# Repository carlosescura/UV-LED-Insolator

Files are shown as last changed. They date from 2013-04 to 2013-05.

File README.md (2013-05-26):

#UV-LED-Insolator#

### UV LED insolator for homemade PCB ###
---------------------------------

  This is a homemade UV-LED insolator aimed to do the "DIY" PCB in home.
  
All you need to build it is:

  1. Two pieces of PCB for the timer and the UV-LED backplate.
  2. An Arduino Mini Pro
  3. Any kind of the popular "16x2" LCD parallel LCD
  4. Some electronics (resistors, pushbuttons, pin headers...)

Let's do it!

More info: [Carlitosspedia](http://www.carlitosspedia.info)

[www.carlitosspedia.info](http://www.carlitosspedia.info)

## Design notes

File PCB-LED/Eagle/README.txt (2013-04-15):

This homemade insolator is designed for a 165x125mm single side board or more.

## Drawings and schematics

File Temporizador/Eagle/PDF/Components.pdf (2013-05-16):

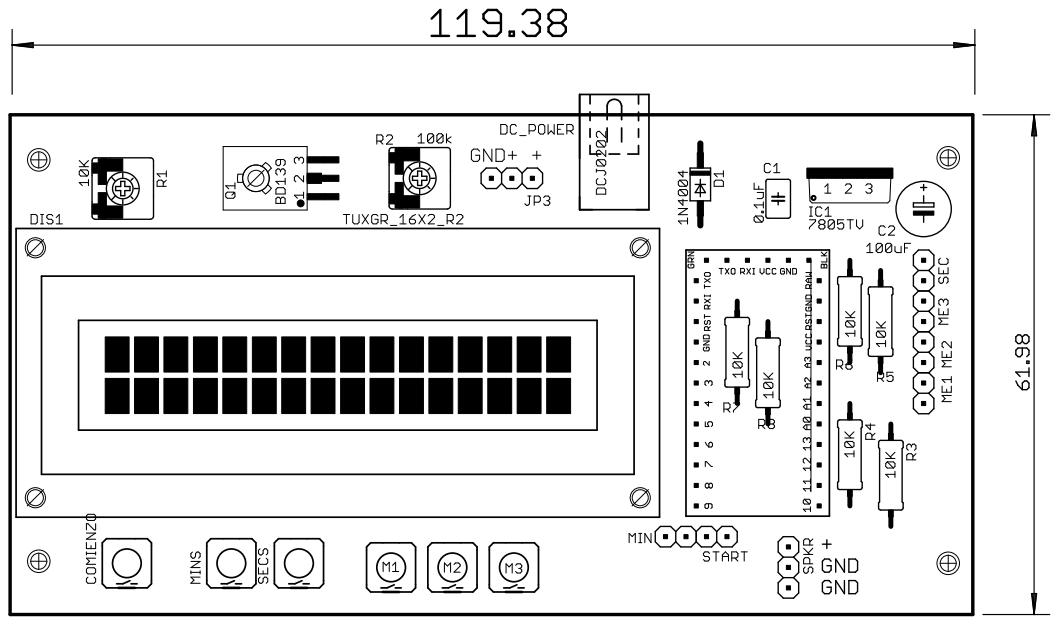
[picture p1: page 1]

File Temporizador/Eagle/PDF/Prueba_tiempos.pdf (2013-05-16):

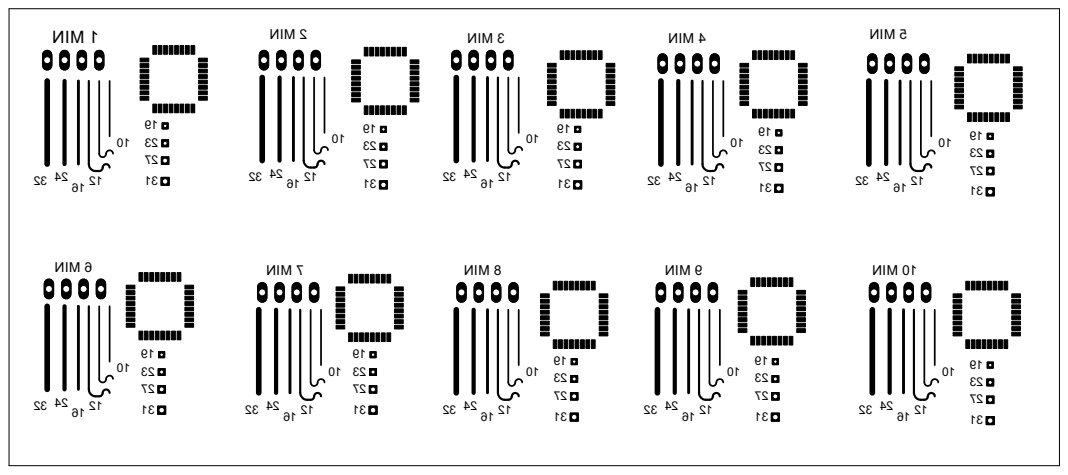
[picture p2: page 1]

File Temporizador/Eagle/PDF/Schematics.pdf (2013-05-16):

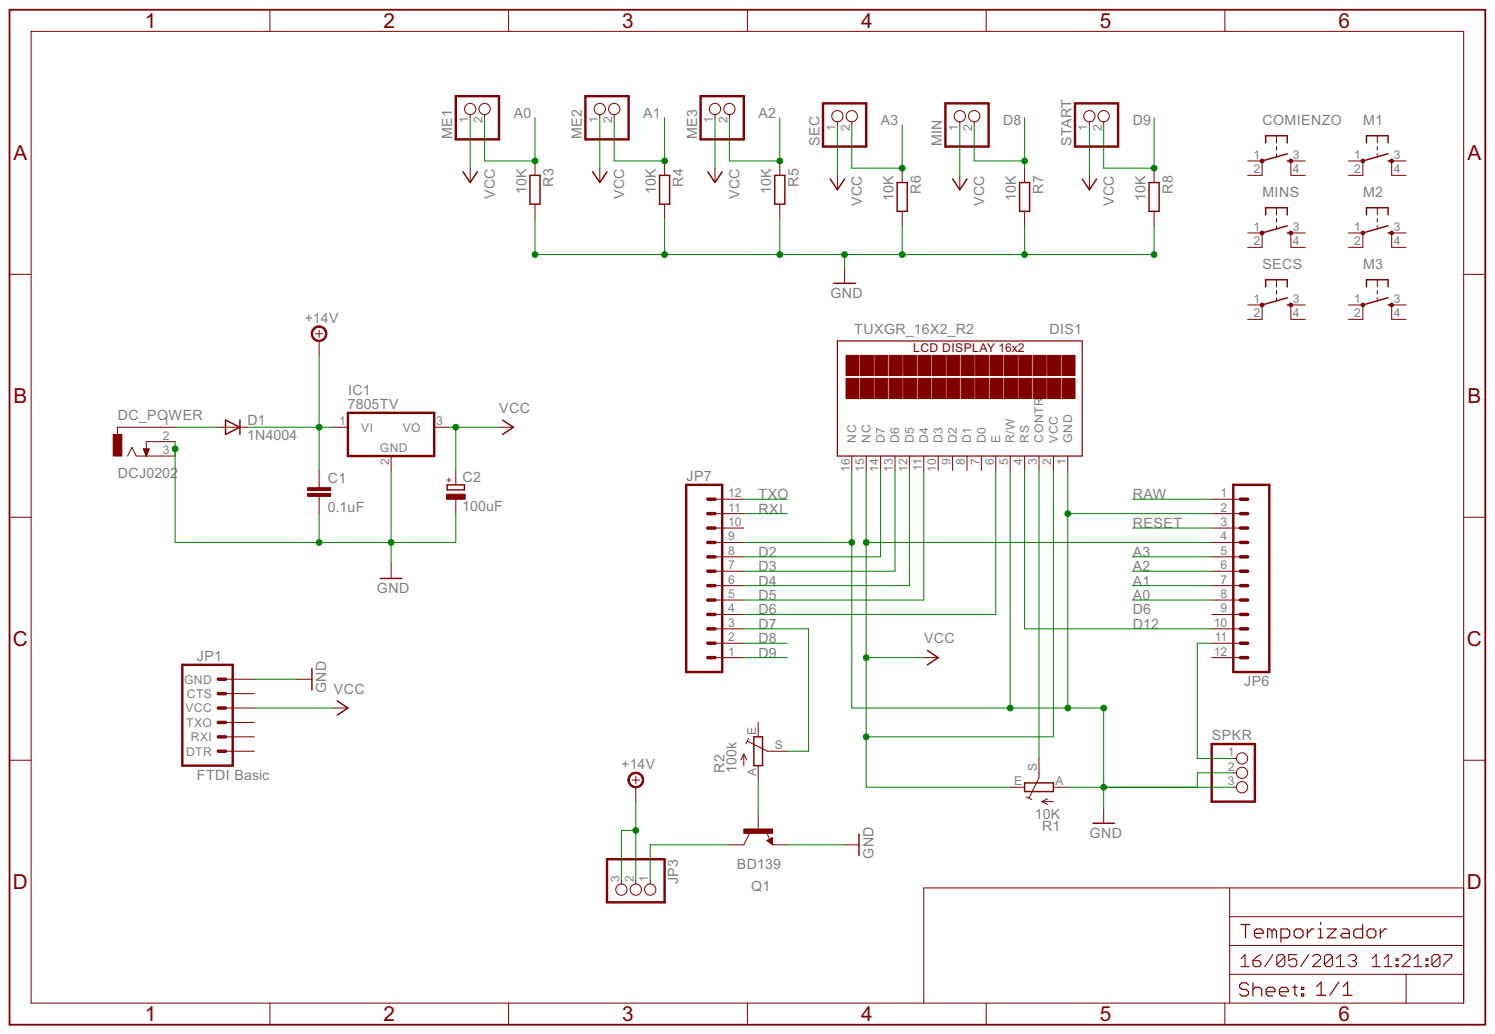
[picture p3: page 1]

8 D2 | A3 5 A2 6 A1 7 A0 8 9 D6 D12
7 D3
6 D4
5 D5
4 D6

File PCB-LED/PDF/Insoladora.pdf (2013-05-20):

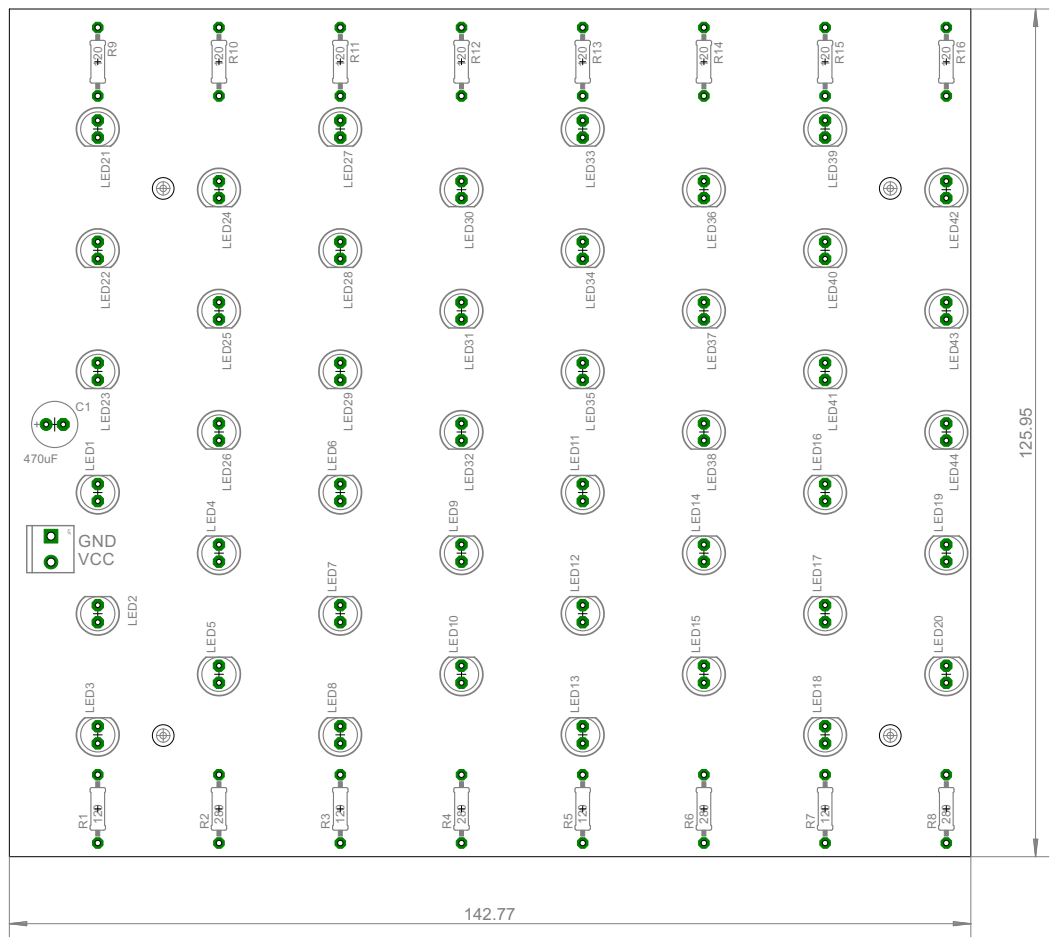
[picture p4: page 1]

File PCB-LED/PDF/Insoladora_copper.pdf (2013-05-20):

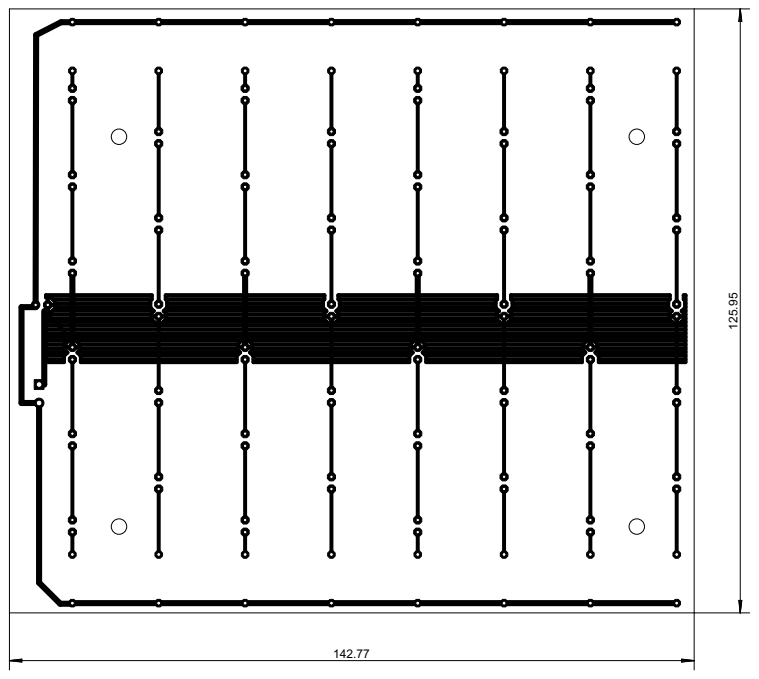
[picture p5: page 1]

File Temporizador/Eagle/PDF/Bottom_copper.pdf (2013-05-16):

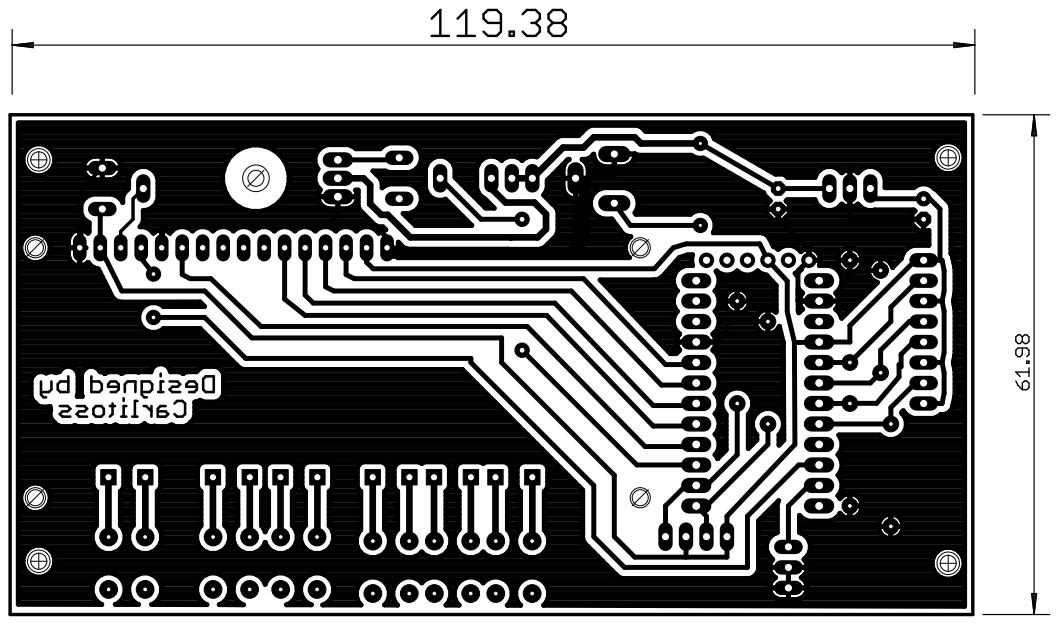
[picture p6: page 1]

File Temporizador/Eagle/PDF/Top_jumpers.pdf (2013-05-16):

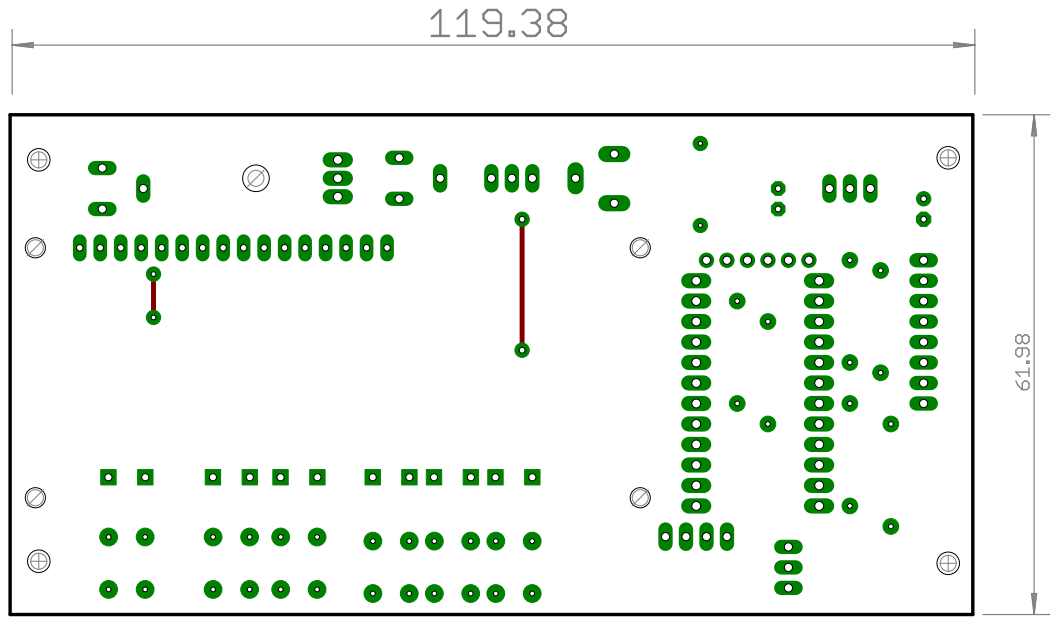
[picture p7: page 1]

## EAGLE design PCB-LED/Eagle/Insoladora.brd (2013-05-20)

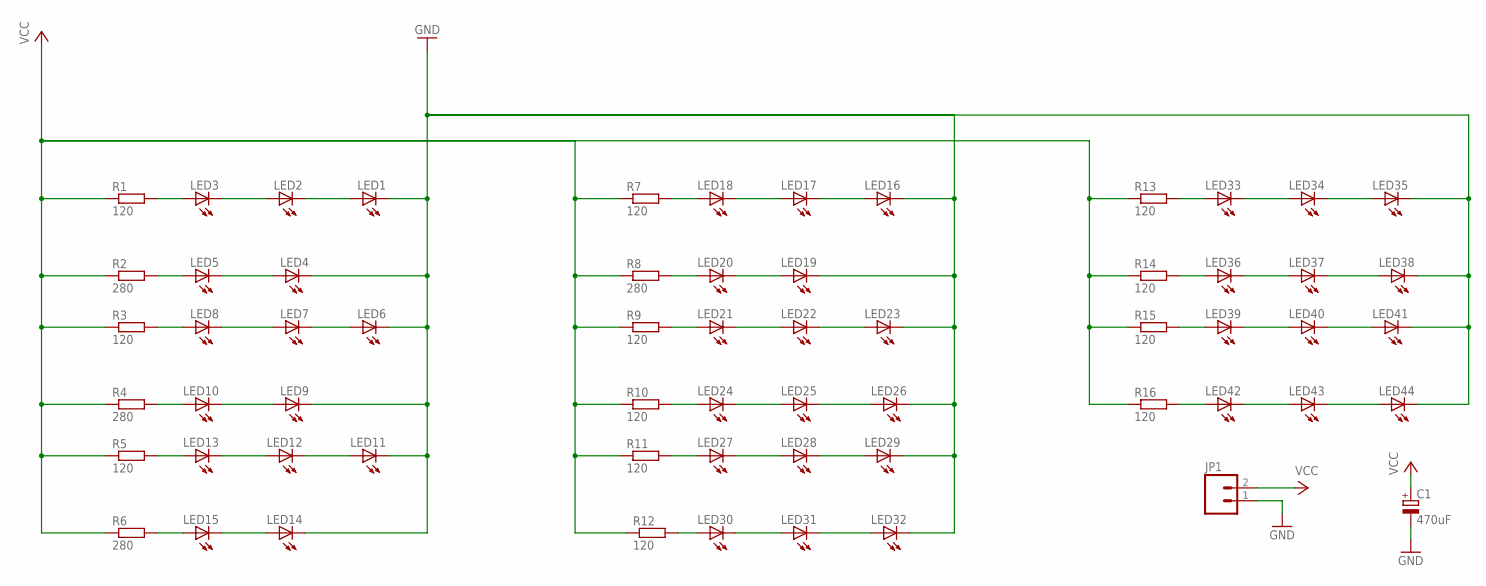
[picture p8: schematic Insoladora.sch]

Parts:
C1: 470uF; E2,5-7
JP1: M023.5MM_LOCK; SCREWTERMINAL-3.5MM-2_LOCK
LED1, LED2, LED3, LED4, LED5, LED6, LED7, LED8, LED9, LED10, LED11, LED12, LED13, LED14, LED15, LED16, LED17, LED18, LED19, LED20, LED21, LED22, LED23, LED24, LED25, LED26, LED27, LED28, LED29, LED30, LED31, LED32, LED33, LED34, LED35, LED36, LED37, LED38, LED39, LED40, LED41, LED42, LED43, LED44: LED5MM
R1, R3, R5, R7, R9, R10, R11, R12, R13, R14, R15, R16: 120; 0207/10
R2, R4, R6, R8: 280; 0207/10

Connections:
GND: C1.-, JP1.1, LED1.K (C), LED4.K (C), LED6.K (C), LED9.K (C), LED11.K (C), LED14.K (C), LED16.K (C), LED19.K (C), LED23.K (C), LED26.K (C), LED29.K (C), LED32.K (C), LED35.K (C), LED38.K (C), LED41.K (C), LED44.K (C)
unnamed: LED3.A, R1.2
unnamed: LED2.A, LED3.K (C)
unnamed: LED1.A, LED2.K (C)
unnamed: LED5.A, R2.2
unnamed: LED4.A, LED5.K (C)
unnamed: LED8.A, R3.2
unnamed: LED7.A, LED8.K (C)
unnamed: LED21.A, R9.2
unnamed: LED6.A, LED7.K (C)
unnamed: LED24.A, R10.2
unnamed: LED10.A, R4.2
unnamed: LED9.A, LED10.K (C)
unnamed: LED30.A, R12.2
unnamed: LED13.A, R5.2
unnamed: LED42.A, R16.2
unnamed: LED21.K (C), LED22.A
unnamed: LED22.K (C), LED23.A
unnamed: LED33.A, R13.2
unnamed: LED18.A, R7.2
unnamed: LED12.A, LED13.K (C)
unnamed: LED17.A, LED18.K (C)
unnamed: LED16.A, LED17.K (C)
unnamed: LED11.A, LED12.K (C)
unnamed: LED24.K (C), LED25.A
unnamed: LED25.K (C), LED26.A
unnamed: LED15.A, R6.2
unnamed: LED27.K (C), LED28.A
unnamed: LED28.K (C), LED29.A
unnamed: LED14.A, LED15.K (C)
unnamed: LED30.K (C), LED31.A
unnamed: LED31.K (C), LED32.A
unnamed: LED20.A, R8.2
unnamed: LED33.K (C), LED34.A
unnamed: LED34.K (C), LED35.A
unnamed: LED19.A, LED20.K (C)
unnamed: LED36.K (C), LED37.A
unnamed: LED37.K (C), LED38.A
unnamed: LED39.K (C), LED40.A
unnamed: LED40.K (C), LED41.A
unnamed: LED42.K (C), LED43.A
unnamed: LED43.K (C), LED44.A
unnamed: LED27.A, R11.2
unnamed: LED36.A, R14.2
unnamed: LED39.A, R15.2
VCC: C1.+, JP1.2, R1.1, R2.1, R3.1, R4.1, R5.1, R6.1, R7.1, R8.1, R9.1, R10.1, R11.1, R12.1, R13.1, R14.1, R15.1, R16.1

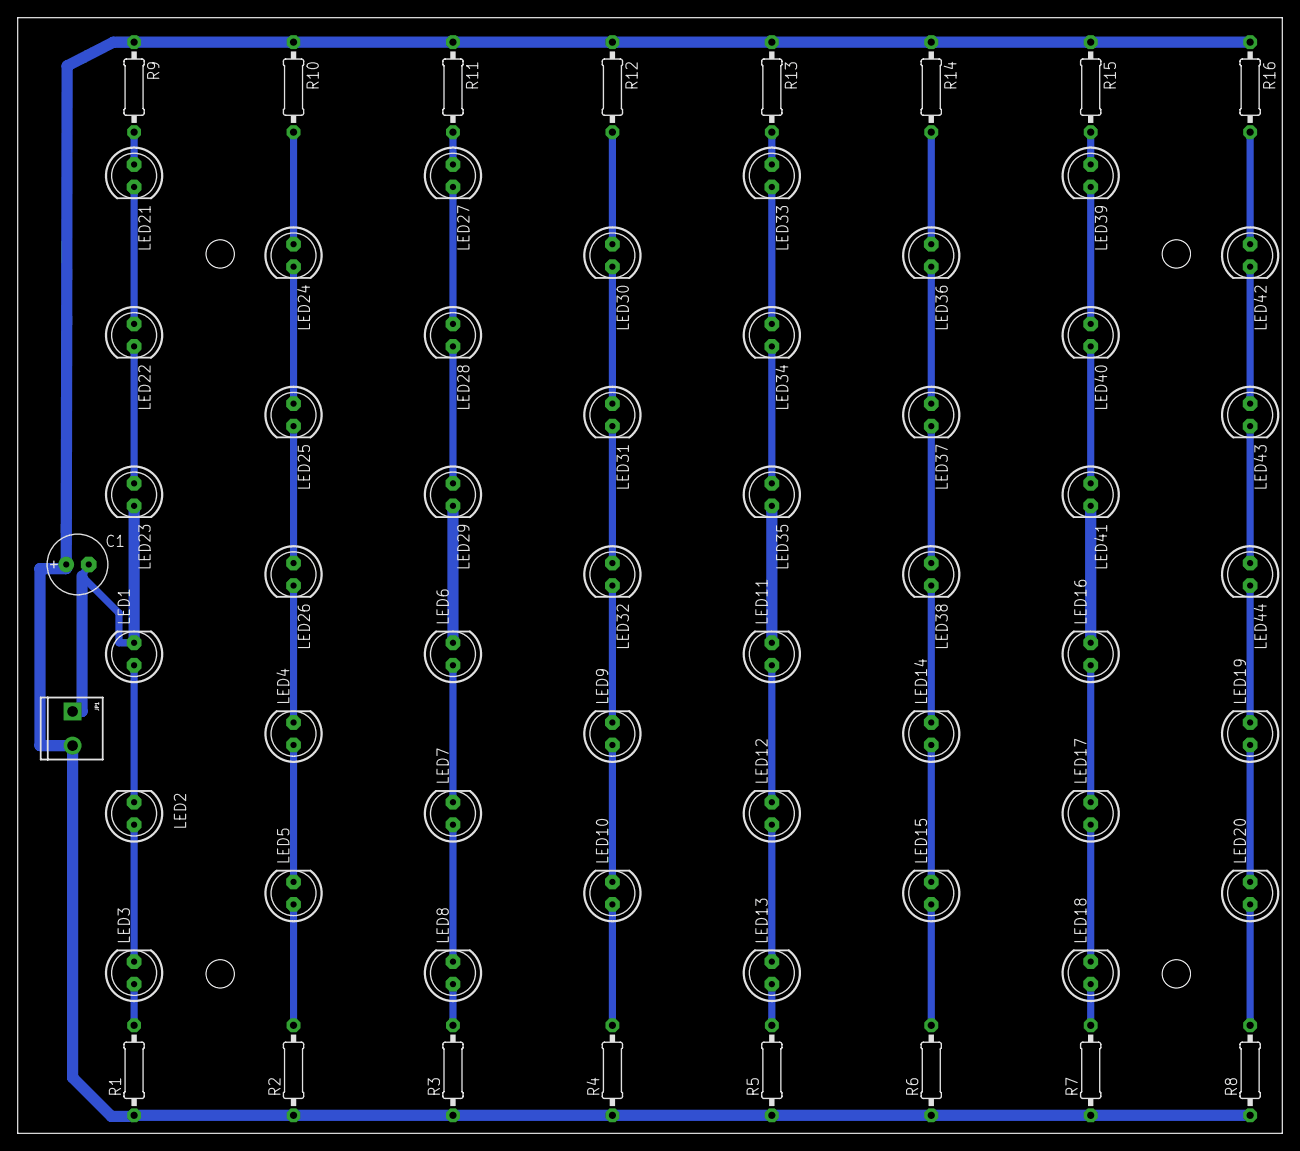
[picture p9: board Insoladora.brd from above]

Board: 2 copper layers, 142.8 x 126.0 mm, 62 parts (0 on the bottom side), 46 nets.

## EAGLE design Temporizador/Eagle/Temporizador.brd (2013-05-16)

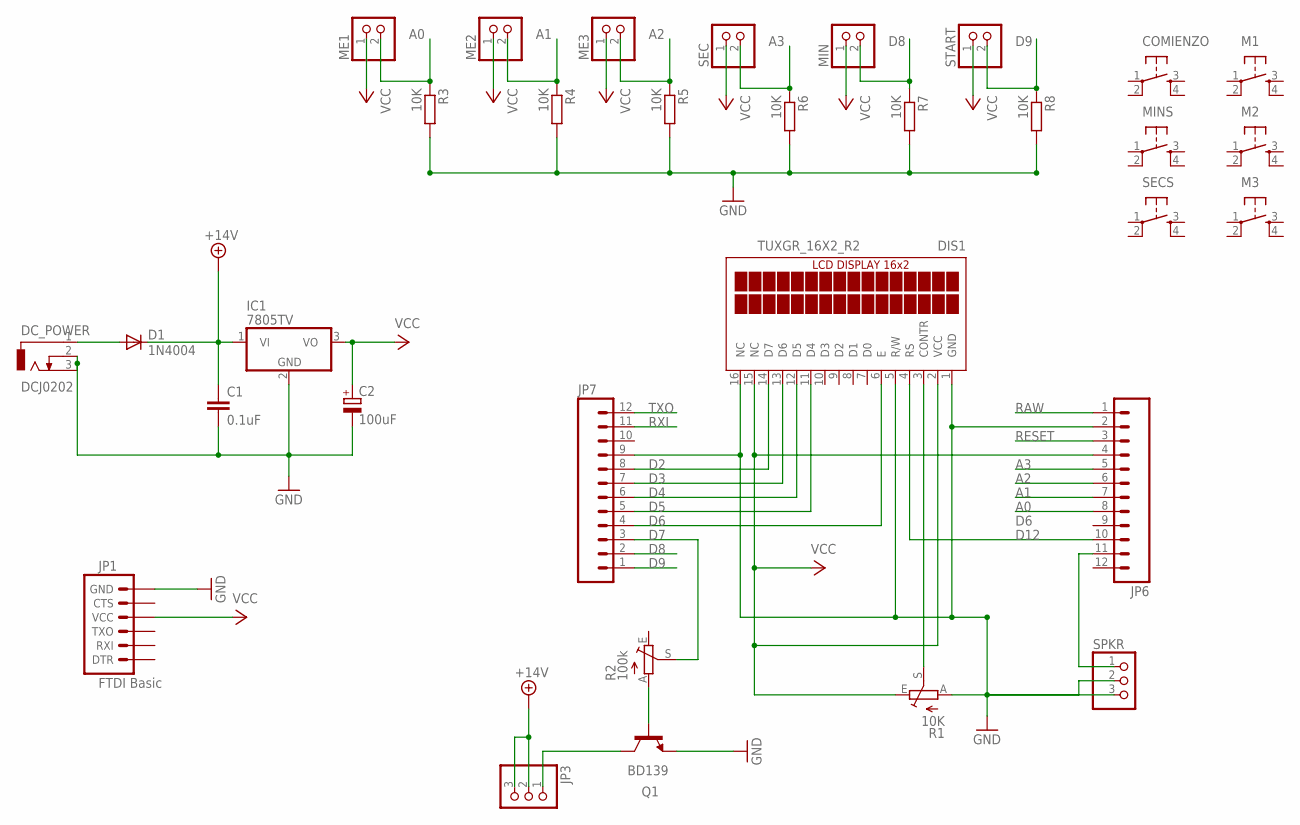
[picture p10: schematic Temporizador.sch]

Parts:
C1: 0.1uF; C025-030X050
C2: 100uF; E2,5-7
COMIENZO: TAC_SWITCHPTH; TACTILE-PTH
D1: 1N4004; DO41-10
DC_POWER: DCJ0202
DIS1: TUXGR_16X2_R2
IC1: 7805TV; TO220V
JP1: FTDI Basic; 1X06
JP3: PINHD-1X3; 1X03
JP6, JP7: M12LONGPADS; 1X12_LONGPADS
M1, M2, M3: TAC_SWITCHPTH; TACTILE-PTH
ME1, ME2, ME3: PINHD-1X2; 1X02
MIN: PINHD-1X2; 1X02
MINS: TAC_SWITCHPTH; TACTILE-PTH
Q1: BD139; TO126
R1: 10K; CA6V
R2: 100k; CA6V
R3, R4, R5, R6, R7, R8: 10K; 0309/12
SEC: PINHD-1X2; 1X02
SECS: TAC_SWITCHPTH; TACTILE-PTH
SPKR: PINHD-1X3; 1X03
START: PINHD-1X2; 1X02

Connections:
+14V: C1.1, D1.C, IC1.1 (VI), JP3.2, JP3.3
A0: JP6.8, ME1.2, R3.1
A1: JP6.7, ME2.2, R4.1
A2: JP6.6, ME3.2, R5.1
A3: JP6.5, R6.1, SEC.2
D2: DIS1.14 (D7), JP7.8
D3: DIS1.13 (D6), JP7.7
D4: DIS1.12 (D5), JP7.6
D5: DIS1.11 (D4), JP7.5
D6: DIS1.6 (E), JP7.4
D7: JP7.3, R2.S
D8: JP7.2, MIN.2, R7.1
D9: JP7.1, R8.1, START.2
D12: DIS1.4 (RS), JP6.10
GND: C1.2, C2.-, DC_POWER.2, DC_POWER.3, DIS1.1 (GND), DIS1.5 (R/W), DIS1.16 (NC), IC1.2 (GND), JP1.6 (GND), JP6.2, JP7.9, Q1.1 (E), R1.A, R3.2, R4.2, R5.2, R6.2, R7.2, R8.2, SPKR.2, SPKR.3
unnamed: DIS1.3 (CONTR), R1.S
unnamed: JP6.11, SPKR.1
unnamed: Q1.3 (B), R2.A
unnamed: JP3.1, Q1.2 (C)
unnamed: D1.A, DC_POWER.1
RAW: JP6.1
RESET: JP6.3
RXI: JP7.11
TXO: JP7.12
VCC: C2.+, DIS1.2 (VCC), DIS1.15 (NC), IC1.3 (VO), JP1.4 (VCC), JP6.4, ME1.1, ME2.1, ME3.1, MIN.1, R1.E, SEC.1, START.1

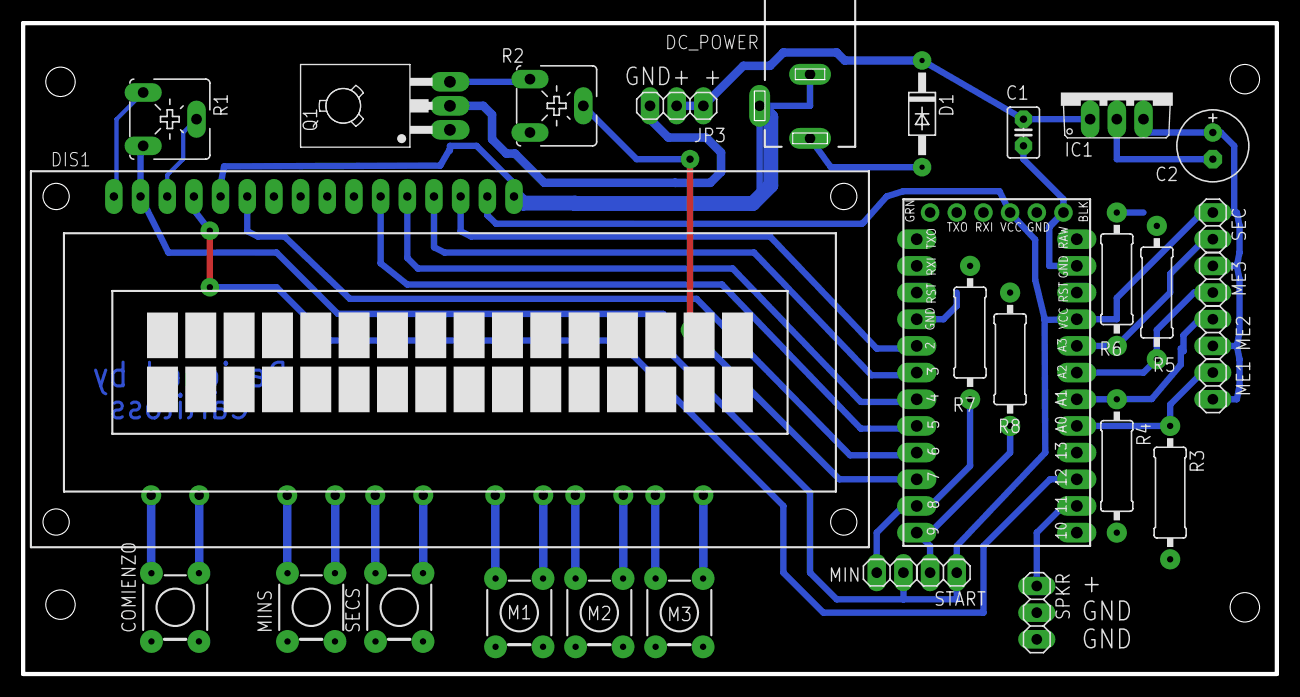
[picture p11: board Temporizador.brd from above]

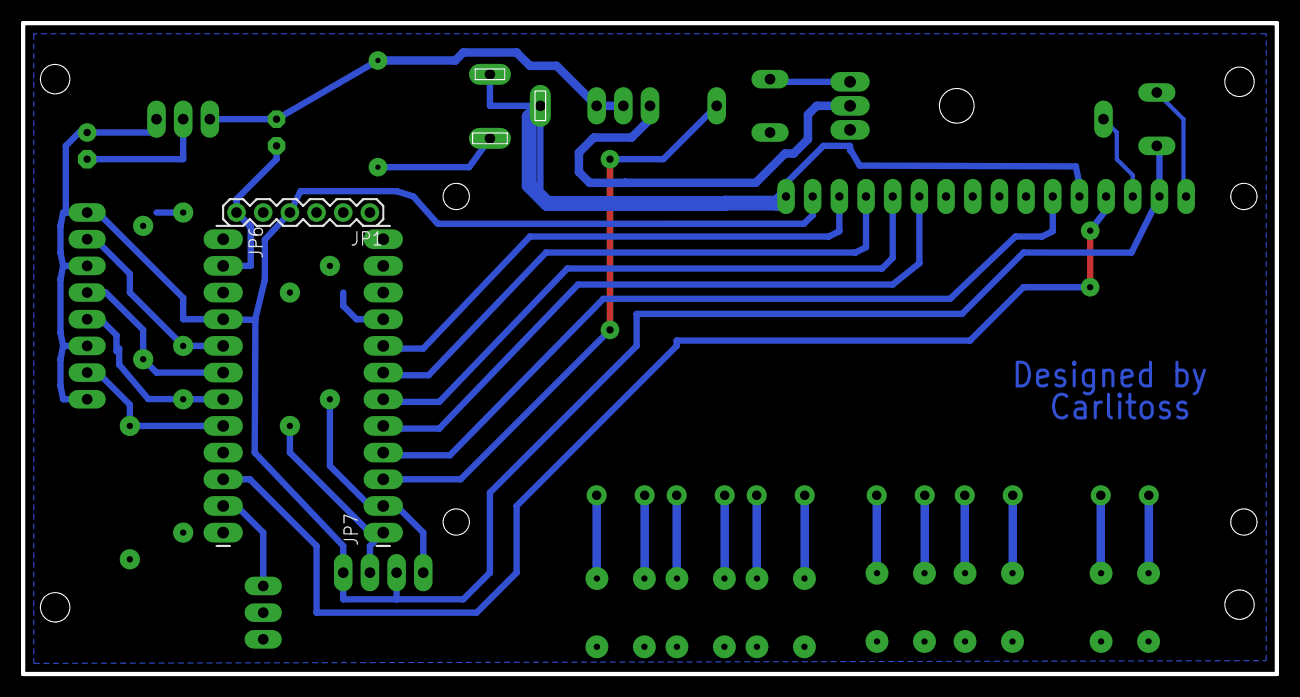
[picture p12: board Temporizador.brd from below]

Board: 2 copper layers, 119.4 x 62.0 mm, 32 parts (3 on the bottom side), 21 nets.

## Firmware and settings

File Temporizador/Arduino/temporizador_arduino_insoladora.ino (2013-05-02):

/*----------------------------------------------------- 
Author:  Carlos Escura
Date: Thu Apr 18 13:55:10 2013
Description:
*/

#include <EEPROM.h>
#include <LiquidCrystal.h>

#define Bpreset1 A0
#define Bpreset2 A1
#define Bpreset3 A2
#define Bsegundos A3
#define Bminutos 8
#define Bcomienzo 9

#define pinSalida 7

#define MApreset1 1
#define MApreset2 2
#define MApreset3 3






//--------------------------CANCIONES----------------------------//

int speakerPin = 11;
//speaker connected to one of the PWM ports
 
#define c 261
#define d 294
#define e 329
#define f 349
#define g 391
#define gS 415
#define a 440
#define aS 455
#define b 466
#define cH 523
#define cSH 554
#define dH 587
#define dSH 622
#define eH 659
#define fH 698
#define fSH 740
#define gH 784
#define gSH 830
#define aH 880


//------------------------//

 
//Tiempo
byte minutos;
byte segundos;

// LiquidCrystal lcd(RS, E, D4, D5, D6, D7);
LiquidCrystal lcd(12, 6, 5, 4, 3, 2);


void setup() {
   
   pinMode(Bcomienzo, INPUT);
   pinMode(Bminutos, INPUT);
   pinMode(Bsegundos, INPUT);
   pinMode(pinSalida, OUTPUT);
   pinMode(Bpreset1, INPUT);
   pinMode(Bpreset2, INPUT);
   pinMode(Bpreset3, INPUT);
   pinMode(speakerPin, OUTPUT); 
   //pinMode(buzzerPin, OUTPUT);
  
  lcd.begin(16, 2);
  lcd.setCursor(3,0);
  lcd.print("INSOLADORA");
  lcd.setCursor(5,1);
  lcd.print("LED-UV");
  delay(3000);
    
  lcd.clear();
  
    
  lcd.setCursor(4,0);
  lcd.print("SELECCION");
  lcd.setCursor(0,1);
  lcd.print("TIEMPO INSOLADO");
  
  delay(3000);
  lcd.clear();
    
  minutos = 0;
  segundos = 0;  
 
}


///////////////-----------------------------------------------------------------/////
//////////////--------------------------MARCHA IMPERIAL ------------------------/////



void beep (unsigned char speakerPin, int frequencyInHertz, long timeInMilliseconds)
{ 
   
    
    int x; 	 
    long delayAmount = (long)(1000000/frequencyInHertz);
    long loopTime = (long)((timeInMilliseconds*1000)/(delayAmount*2));
    for (x=0;x<loopTime;x++) 	 
    { 	 
        digitalWrite(speakerPin,HIGH);
        delayMicroseconds(delayAmount);
        digitalWrite(speakerPin,LOW);
        delayMicroseconds(delayAmount);
    } 	 
    
   
    
    delay(20);
    //a little delay to make all notes sound separate
} 	 
  	 
void march()
{ 
    
    beep(speakerPin, a, 500); 
    beep(speakerPin, a, 500);     
    beep(speakerPin, a, 500); 
    beep(speakerPin, f, 350); 
    beep(speakerPin, cH, 150);
    
    beep(speakerPin, a, 500);
    beep(speakerPin, f, 350);
    beep(speakerPin, cH, 150);
    beep(speakerPin, a, 1000);
    //first bit
    
    beep(speakerPin, eH, 500);
    beep(speakerPin, eH, 500);
    beep(speakerPin, eH, 500);    
    beep(speakerPin, fH, 350); 
    beep(speakerPin, cH, 150);
    
    beep(speakerPin, gS, 500);
    beep(speakerPin, f, 350);
    beep(speakerPin, cH, 150);
    beep(speakerPin, a, 1000);
    //second bit...
    
    beep(speakerPin, aH, 500);
    beep(speakerPin, a, 350); 
    beep(speakerPin, a, 150);
    beep(speakerPin, aH, 500);
    beep(speakerPin, gSH, 250); 
    beep(speakerPin, gH, 250);
    
    beep(speakerPin, fSH, 125);
    beep(speakerPin, fH, 125);    
    beep(speakerPin, fSH, 250);
    delay(250);
    beep(speakerPin, aS, 250);    
    beep(speakerPin, dSH, 500);  
    beep(speakerPin, dH, 250);  
    beep(speakerPin, cSH, 250);  
    //start of the interesting bit
    
    beep(speakerPin, cH, 125);  
    beep(speakerPin, b, 125);  
    beep(speakerPin, cH, 250);      
    delay(250);
    beep(speakerPin, f, 125);  
    beep(speakerPin, gS, 500);  
    beep(speakerPin, f, 375);  
    beep(speakerPin, a, 125); 
    
    beep(speakerPin, cH, 500); 
    beep(speakerPin, a, 375);  
    beep(speakerPin, cH, 125); 
    beep(speakerPin, eH, 1000); 
    //more interesting stuff (this doesn't quite get it right somehow)
    
    beep(speakerPin, aH, 500);
    beep(speakerPin, a, 350); 
    beep(speakerPin, a, 150);
    beep(speakerPin, aH, 500);
    beep(speakerPin, gSH, 250); 
    beep(speakerPin, gH, 250);
    
    beep(speakerPin, fSH, 125);
    beep(speakerPin, fH, 125);    
    beep(speakerPin, fSH, 250);
    delay(250);
    beep(speakerPin, aS, 250);    
    beep(speakerPin, dSH, 500);  
    beep(speakerPin, dH, 250);  
    beep(speakerPin, cSH, 250);  
    //repeat... repeat
    
    beep(speakerPin, cH, 125);  
    beep(speakerPin, b, 125);  
    beep(speakerPin, cH, 250);      
    delay(250);
    beep(speakerPin, f, 250);  
    beep(speakerPin, gS, 500);  
    beep(speakerPin, f, 375);  
    beep(speakerPin, cH, 125); 
           
    beep(speakerPin, a, 500);            
    beep(speakerPin, f, 375);            
    beep(speakerPin, c, 125);            
    beep(speakerPin, a, 1000);       
    //and we're done \ó/    
}





void imprime_guardando(byte memo){
  lcd.clear();
  lcd.setCursor(3,0);
  lcd.print("GUARDANDO ");
  lcd.setCursor(3,1);
  lcd.print("MEMORIA ");
  lcd.setCursor(11,1);
  lcd.print(memo, 10);
  delay(1500);
}

void imprime_leyendo(int val){
  lcd.clear();
  lcd.setCursor(4,0);
  lcd.print("LEYENDO");
  lcd.setCursor(3,1);
  lcd.print("MEMORIA");
  lcd.setCursor(11,1);
  lcd.print(val, 10);
  delay(2000);
  lcd.clear();

}
void imprime_guardado_completo(){
  lcd.clear();
  lcd.setCursor(4,0);
  lcd.print("Success!");
  delay(1500);

}
void anti_rebote_minutos (){

if (digitalRead(Bminutos)==HIGH){
    delay(40);
    if (digitalRead(Bminutos) == HIGH){
    minutos += 1;
    delay(90);
    }
   }
   }
   
   
void anti_rebote_segundos (){

if (digitalRead(Bsegundos)==HIGH){
    delay(40);
    if (digitalRead(Bsegundos) == HIGH){
    if(segundos <=58){
    segundos += 1;
    }else if(segundos = 59){
    //limpiar caracter lcd
    lcd.clear();
    segundos = 0;
    minutos += 1;
    }
    delay(50);
    }
   }
   }
   

void print_comienzo(){
    
    lcd.clear();
    lcd.setCursor(4,0);
    lcd.print("Let's Go");
    delay(2500);
    lcd.clear();

}

void print_cuenta_atras(){

do{

  if (segundos > 0){
             
      lcd.clear();
      lcd.setCursor(0,0);
      lcd.print("MINUTOS: ") ;
      lcd.print(minutos, 10);
      lcd.setCursor(0,1);
      lcd.print("SEGUNDOS: ");
      lcd.print(segundos, 10);
      delay (1000);
      segundos --;   
     
    
  }
   
  if (minutos > 0){
      if (segundos <= 0){
      minutos--;
      segundos = 59; 
      }
  
  }
 }while (segundos != 0);

}

void print_finalizado(){

  lcd.clear();
  lcd.setCursor(3,0);
  lcd.print("INSOLACION");
  lcd.setCursor(3,1);
  lcd.print("FINALIZADA");
  delay(3000);
  lcd.clear();
  lcd.setCursor(3,0);
  lcd.print("Thinking4u");
  lcd.setCursor(0,2);
  lcd.print("Design Carlitoss");


}


void check_preset(byte button, byte memoryAddress){
    
    if (digitalRead(button)==HIGH){
        delay(10);
        if(digitalRead(button)==HIGH){
            delay(1000);
            if (digitalRead(button) == LOW){
               //Se ha soltado, leemos de eeprom
               imprime_leyendo(memoryAddress);
               minutos = EEPROM.read(memoryAddress); 
               delay(100);
               segundos = EEPROM.read(memoryAddress+10);
               delay(100);
               lcd.clear();
               
            } else if (digitalRead(button) == HIGH){    //Sigue pulsado write a eeprom
               imprime_guardando(memoryAddress);
               delay(100);
               EEPROM.write(memoryAddress, minutos);
               delay(100);
               lcd.clear();
               //imprime_guardando(segundos);
               EEPROM.write(memoryAddress+10, segundos);
               delay(500); 
               imprime_guardado_completo();
               delay(500);
               lcd.clear();
            }
        }
    }
}




void loop() {
 
 
   anti_rebote_minutos();
   anti_rebote_segundos();
   check_preset(Bpreset1, MApreset1);
   check_preset(Bpreset2, MApreset2);
   check_preset(Bpreset3, MApreset3);
   delay(20);
     

   lcd.setCursor(0,0);
   lcd.print("MINUTOS: ");
   lcd.print(minutos,10);
   lcd.setCursor(0,1);
   lcd.print("SEGUNDOS: ");
   lcd.print(segundos,10);
   
   if(digitalRead(Bcomienzo) == HIGH){
      delay (40);
      if(digitalRead(Bcomienzo) == HIGH){
        print_comienzo();
        digitalWrite(pinSalida, 1);
        print_cuenta_atras();
        digitalWrite(pinSalida, 0);
        print_finalizado();
        march();
        lcd.clear();
      }
   }

}

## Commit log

2013-04-15 PCB ver 1.0
    First version of the PCB insolator
    [Insoladora.brd, Insoladora.sch]
2013-05-02 Added timer to the project
    Added a timer to the project with LCD based on Arduino Pro mini
    [Insoladora.brd, Insoladora.sch, Temporizador.brd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]
2013-05-16 Board v1.2
    Added more useful pins, comments and larger pads for better soldering
    [Temporizador.brd, Temporizador.sch]
2013-05-20 Board v1.3
    Added new power supply connector and bigger pads for ease soldering
    [Insoladora.brd, Insoladora.sch]

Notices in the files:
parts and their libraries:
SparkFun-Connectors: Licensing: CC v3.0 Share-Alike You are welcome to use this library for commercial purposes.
